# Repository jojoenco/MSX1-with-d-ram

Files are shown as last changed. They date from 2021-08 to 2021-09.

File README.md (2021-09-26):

# MSX1-with-d-ram
MSX1 compatible machine with old fashion D-Ram

Specs:  
Z80  
TMS9918 (composiet out)  
8255  
AY-3-8910  
HM4816 X8 V-Ram  
HM4864 X8 Ram  
74xx  logic IC's  

Tested until version 2.5 
This is version 2.6 should work as I only removed the Opamp for audio out and chanced the Transistor for the (Cassete)relay that
probably nobody uses. (because there is also a jack in and out for the cassete)

What works and tested in version 2.5:
- [x] Boot with MSX-Bios and C-Bios 
- [x] Video Out
- [x] audio out (sound was bad in version 2.5 so removed Opamp in 2.6)
- [x] Joystick ports
- [x] cassete in through 3.5"mm jack
- [ ] cassete out not tested
- [ ] Cassete DIN not tested
- [ ] relay (for Cassete REM) did not switch in version 2.5 (chanced transistor but not tested yet)
- [x] reset
- [X] Keyboard 
- [X] Cartridge Slot 1 and Slot2
- [ ] Printer port not tested

Because there is only a matrix connection for the keyboard I used the keyboard from Sergey Kiselev (github.com/skiselev/omega) to test.
I used the keyboard without de chips on it because they are on the main board and I jumpered on U2 the pins 1-2 and 3-4 and 5-6 and 8-9.
And then connected the wires directly to U1 pin 1-9 and J1 the bottom row.

My own keyboard PCB is ready but I am waiting for the switches to test it.

THE KEYBOARD  
The switches came in and it works fine:  
https://github.com/jojoenco/Keyboard-for-MSX1-with-d-ram

Below a foto of version 2.0 

And more Below Version 2.6 with no components yet





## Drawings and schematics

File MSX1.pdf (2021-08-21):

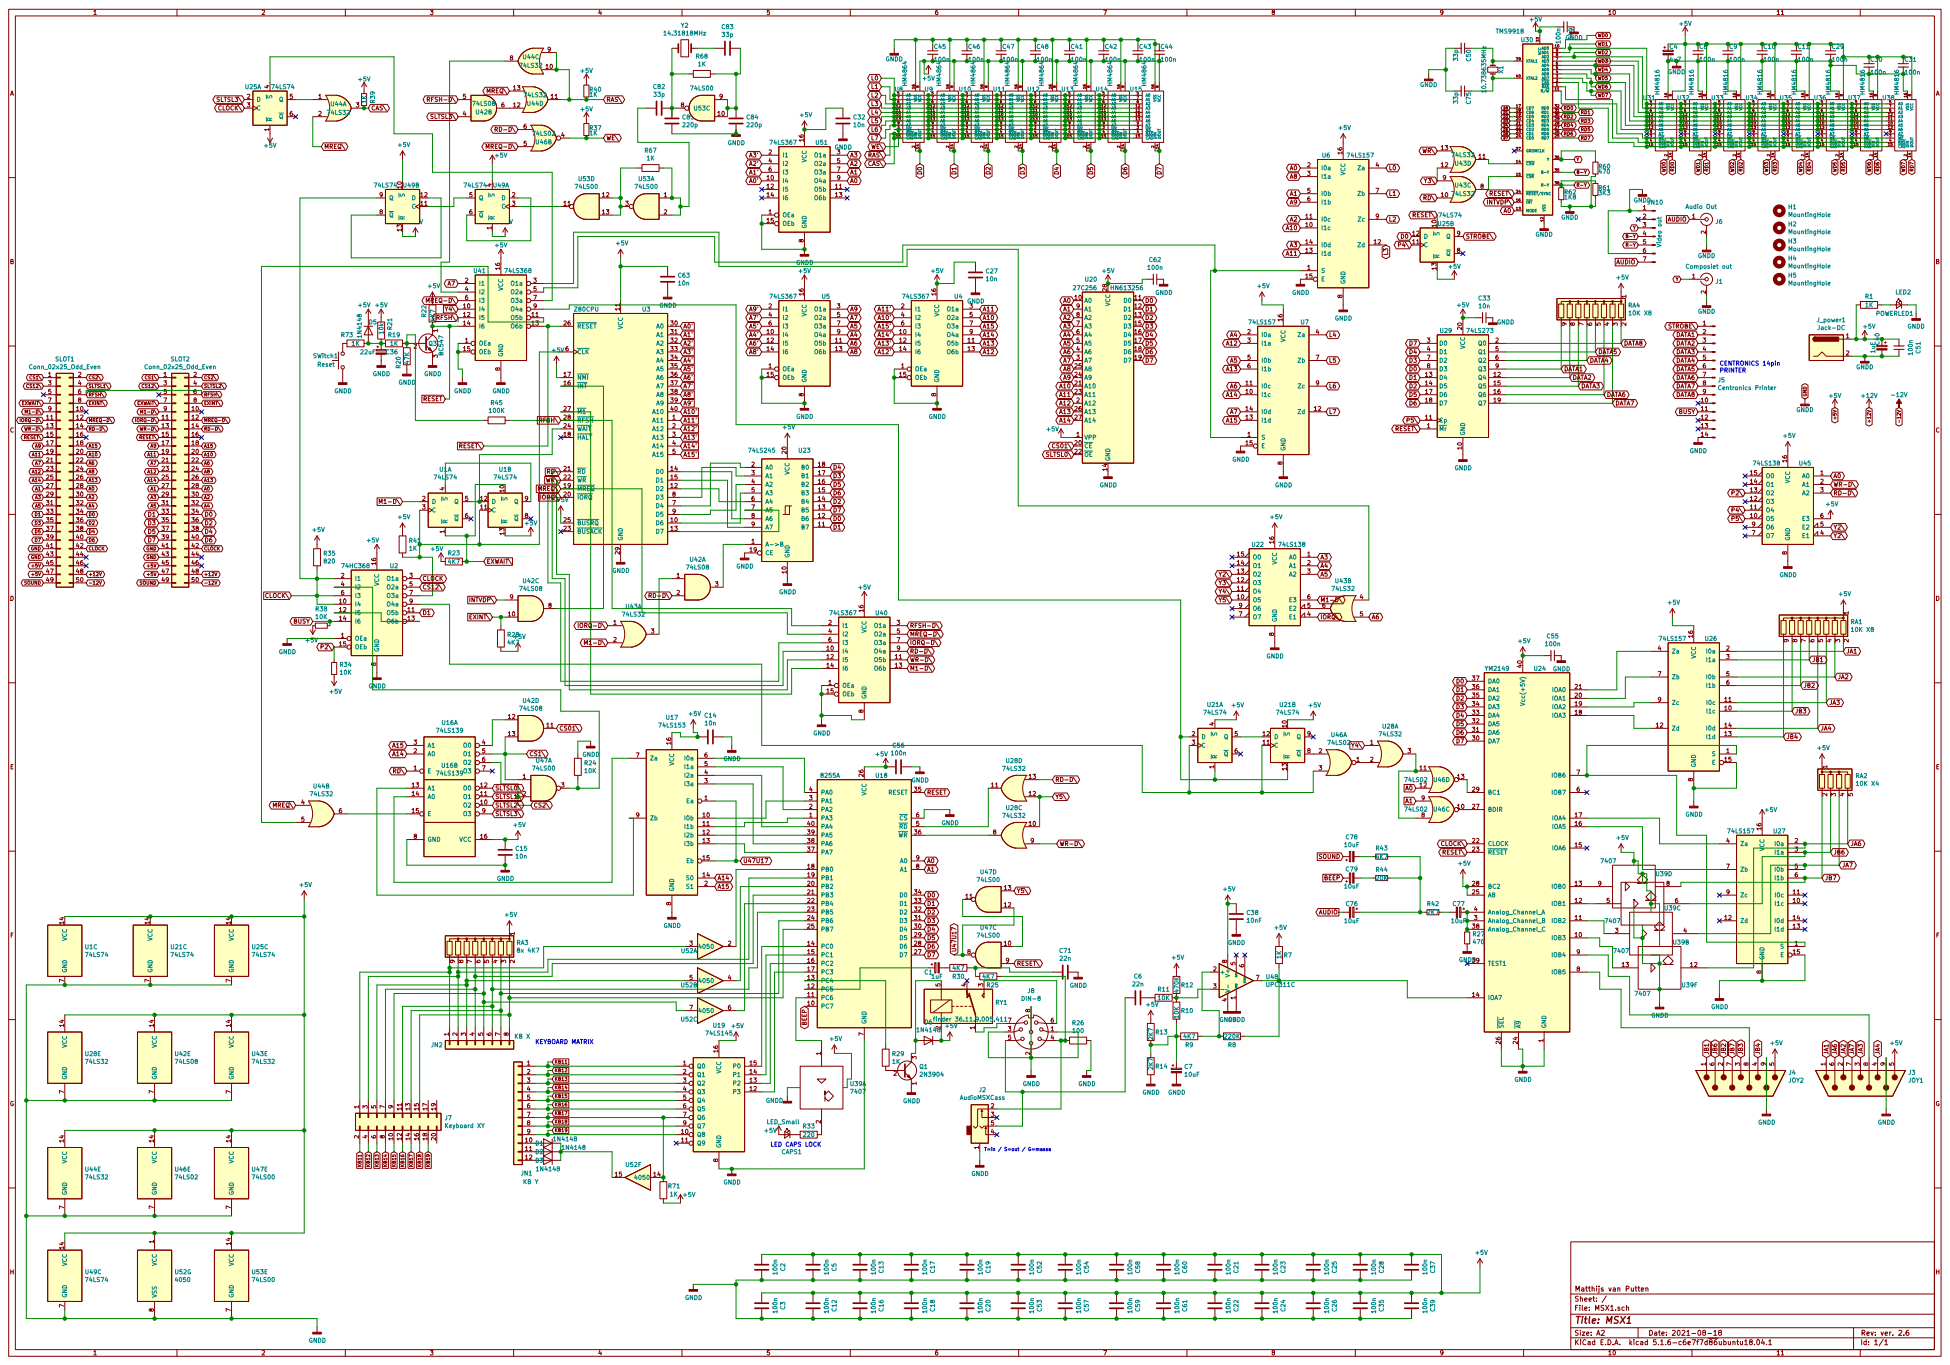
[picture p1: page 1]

8 A7 9 U10 HM4864 PA3 1 PC7 10 PC6 11 PC5 12 PC4 13 PC0 14 PC1 15 PC2 16 PC3 17 PB0 18 PB1 19 PA2 2 PB2 20 PB3 21 PB4 22 PB5 23 PB6 24 PB7 25 VCC 26 D7 27 D6 28 D5 29 PA1 3 D4 30 D3 31 D2 32 D1 33 D0 34 RESET 35 WR 36 PA7 37 PA6 38 PA5 39 PA0 4 PA4 40 RD 5 CS 6 GND

J6 Audio Out VCC 14 GND

T=in / S=out / G=massa KEYBOARD MATRIX

Id: 1/1 Title: MSX1 File: MSX1.sch Sheet: / Matthijs van Putten

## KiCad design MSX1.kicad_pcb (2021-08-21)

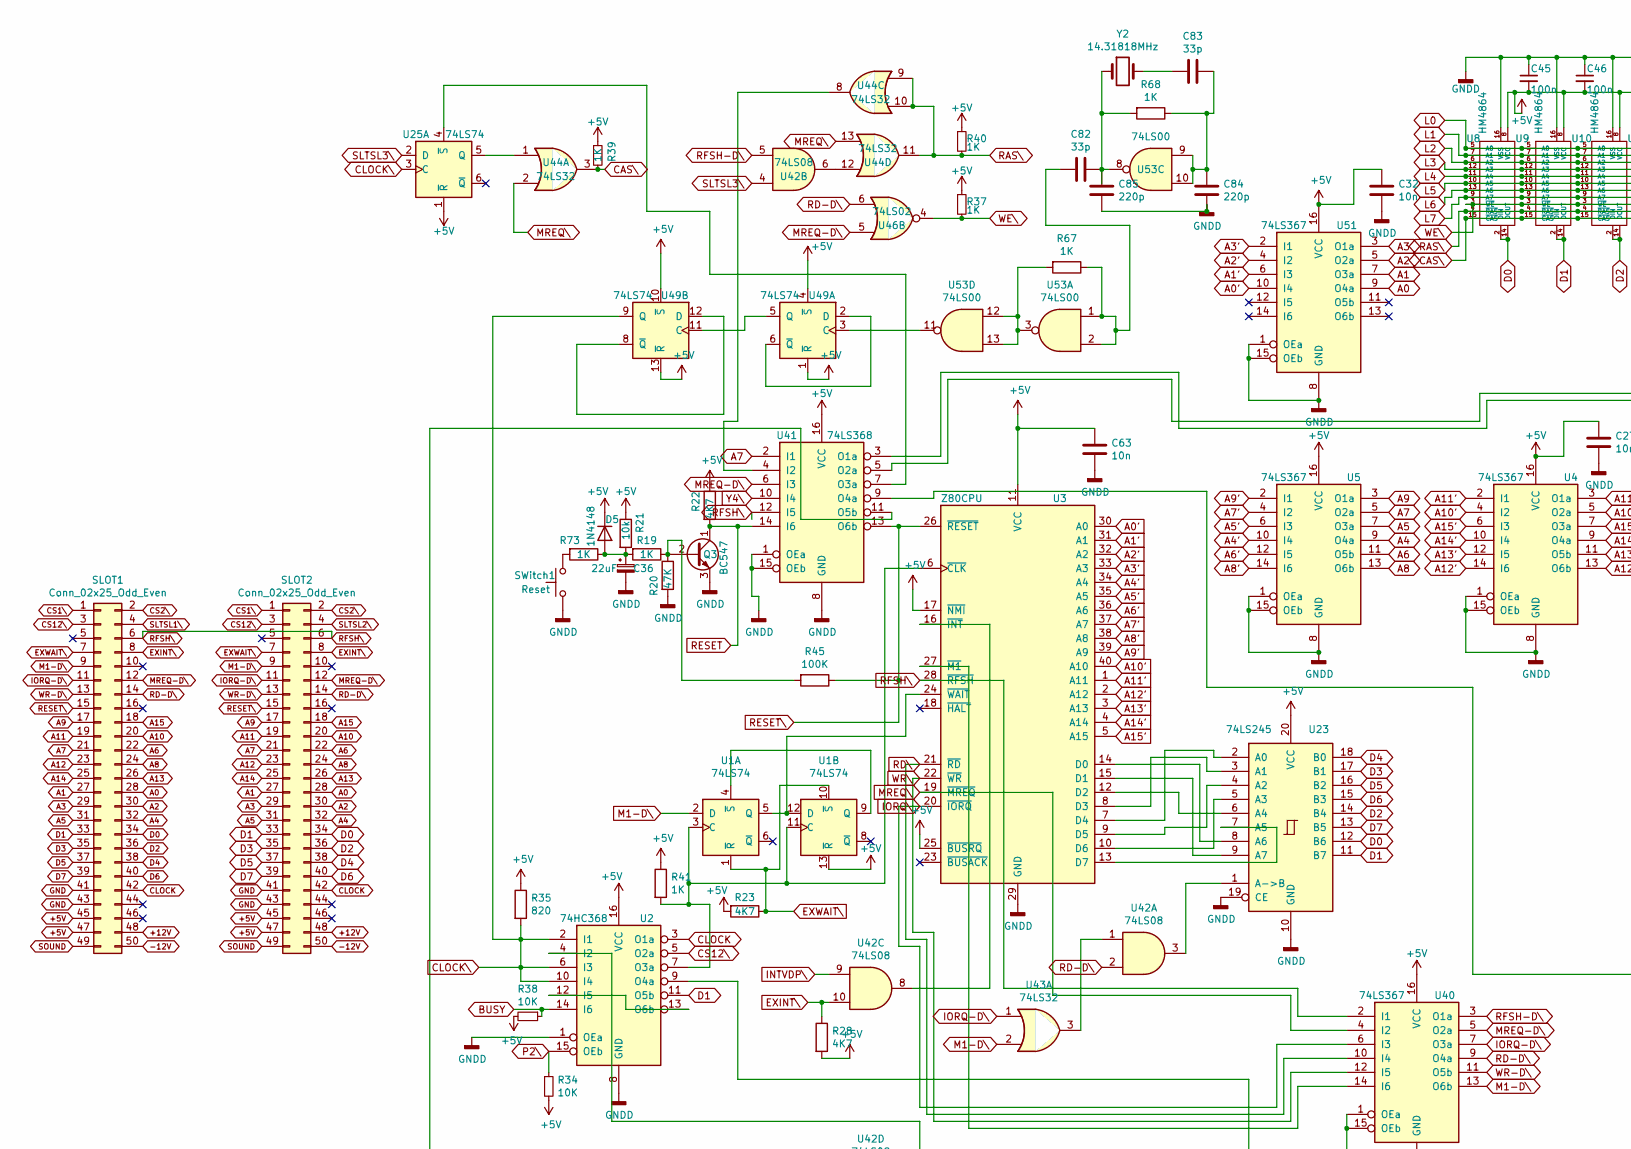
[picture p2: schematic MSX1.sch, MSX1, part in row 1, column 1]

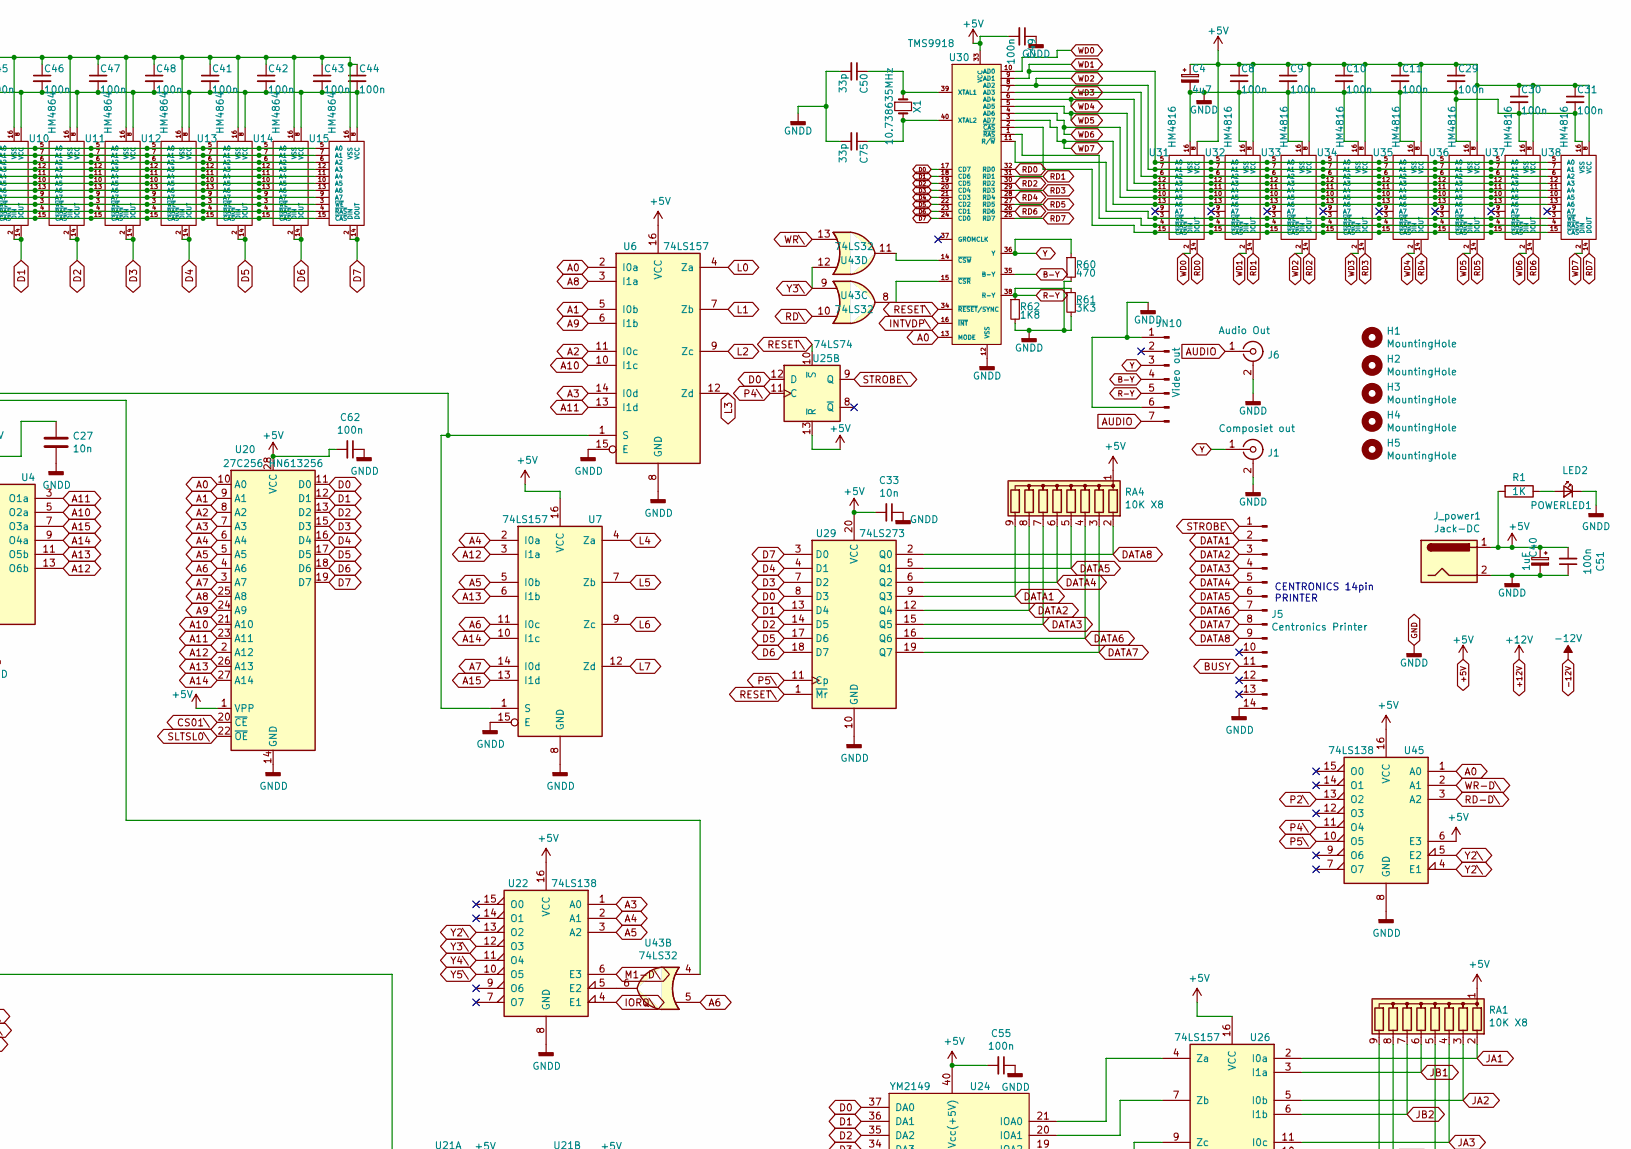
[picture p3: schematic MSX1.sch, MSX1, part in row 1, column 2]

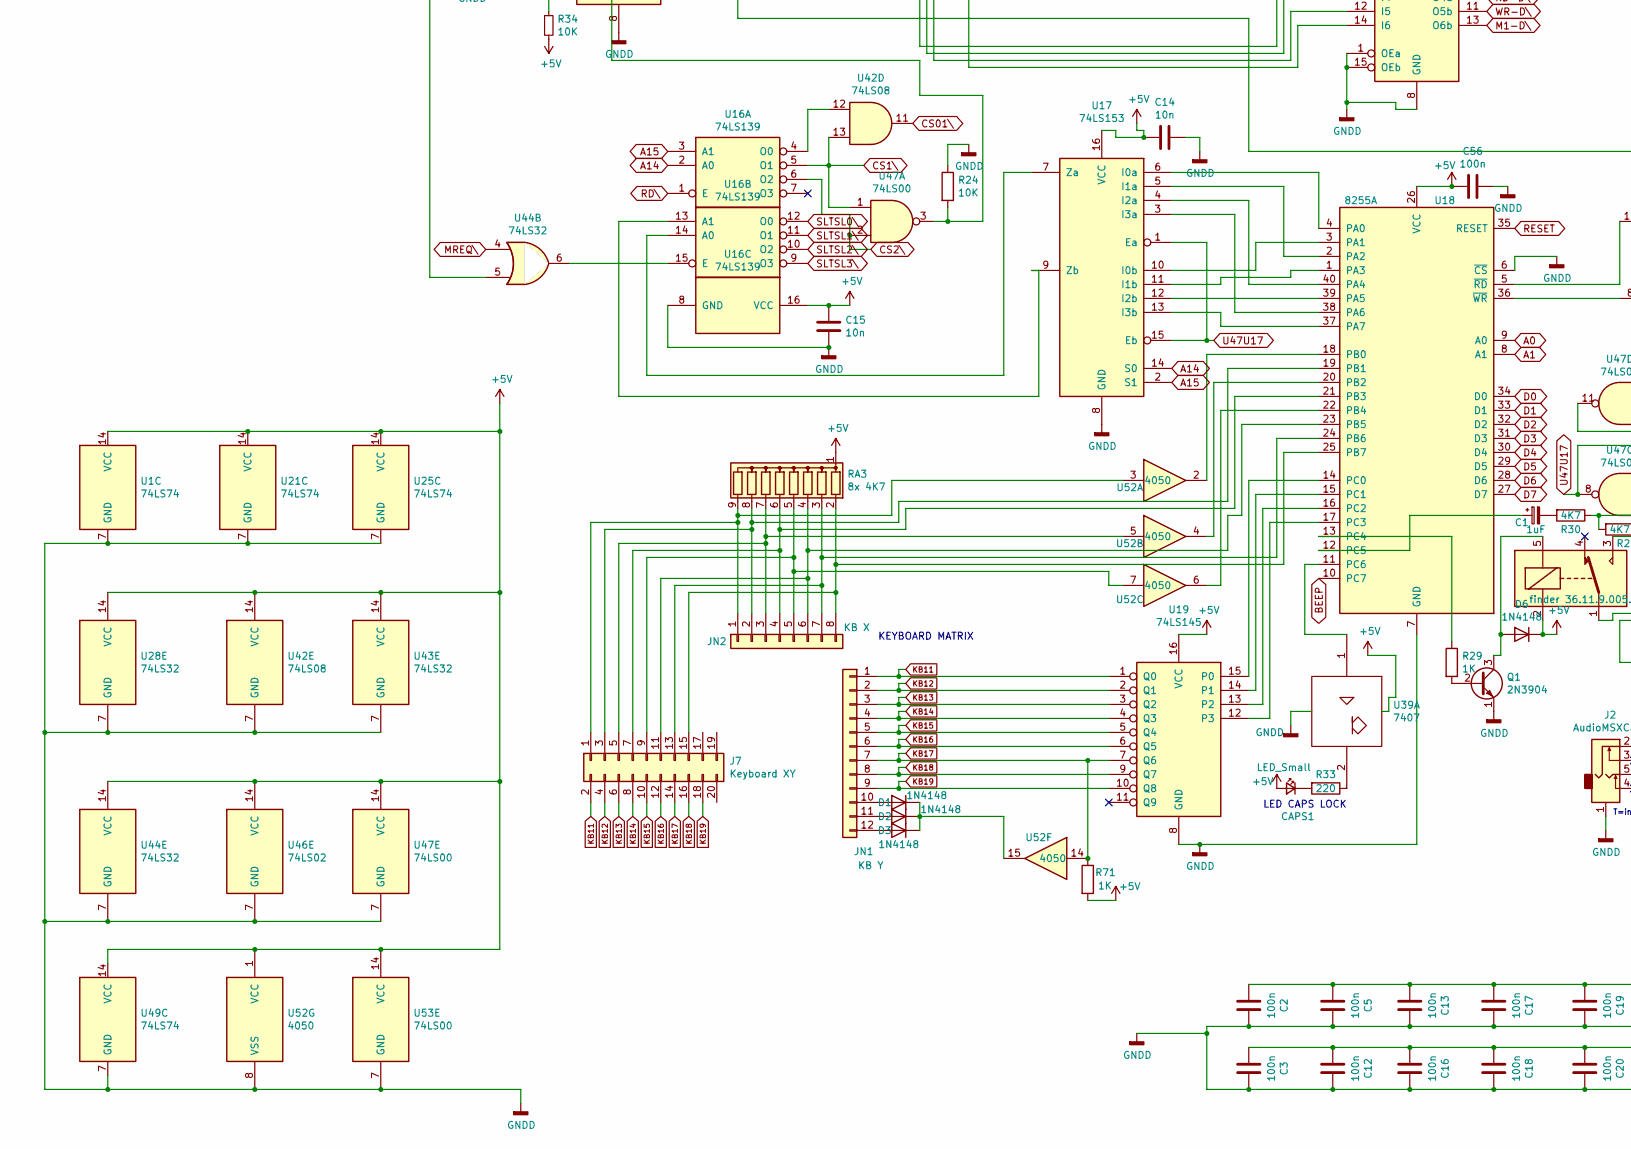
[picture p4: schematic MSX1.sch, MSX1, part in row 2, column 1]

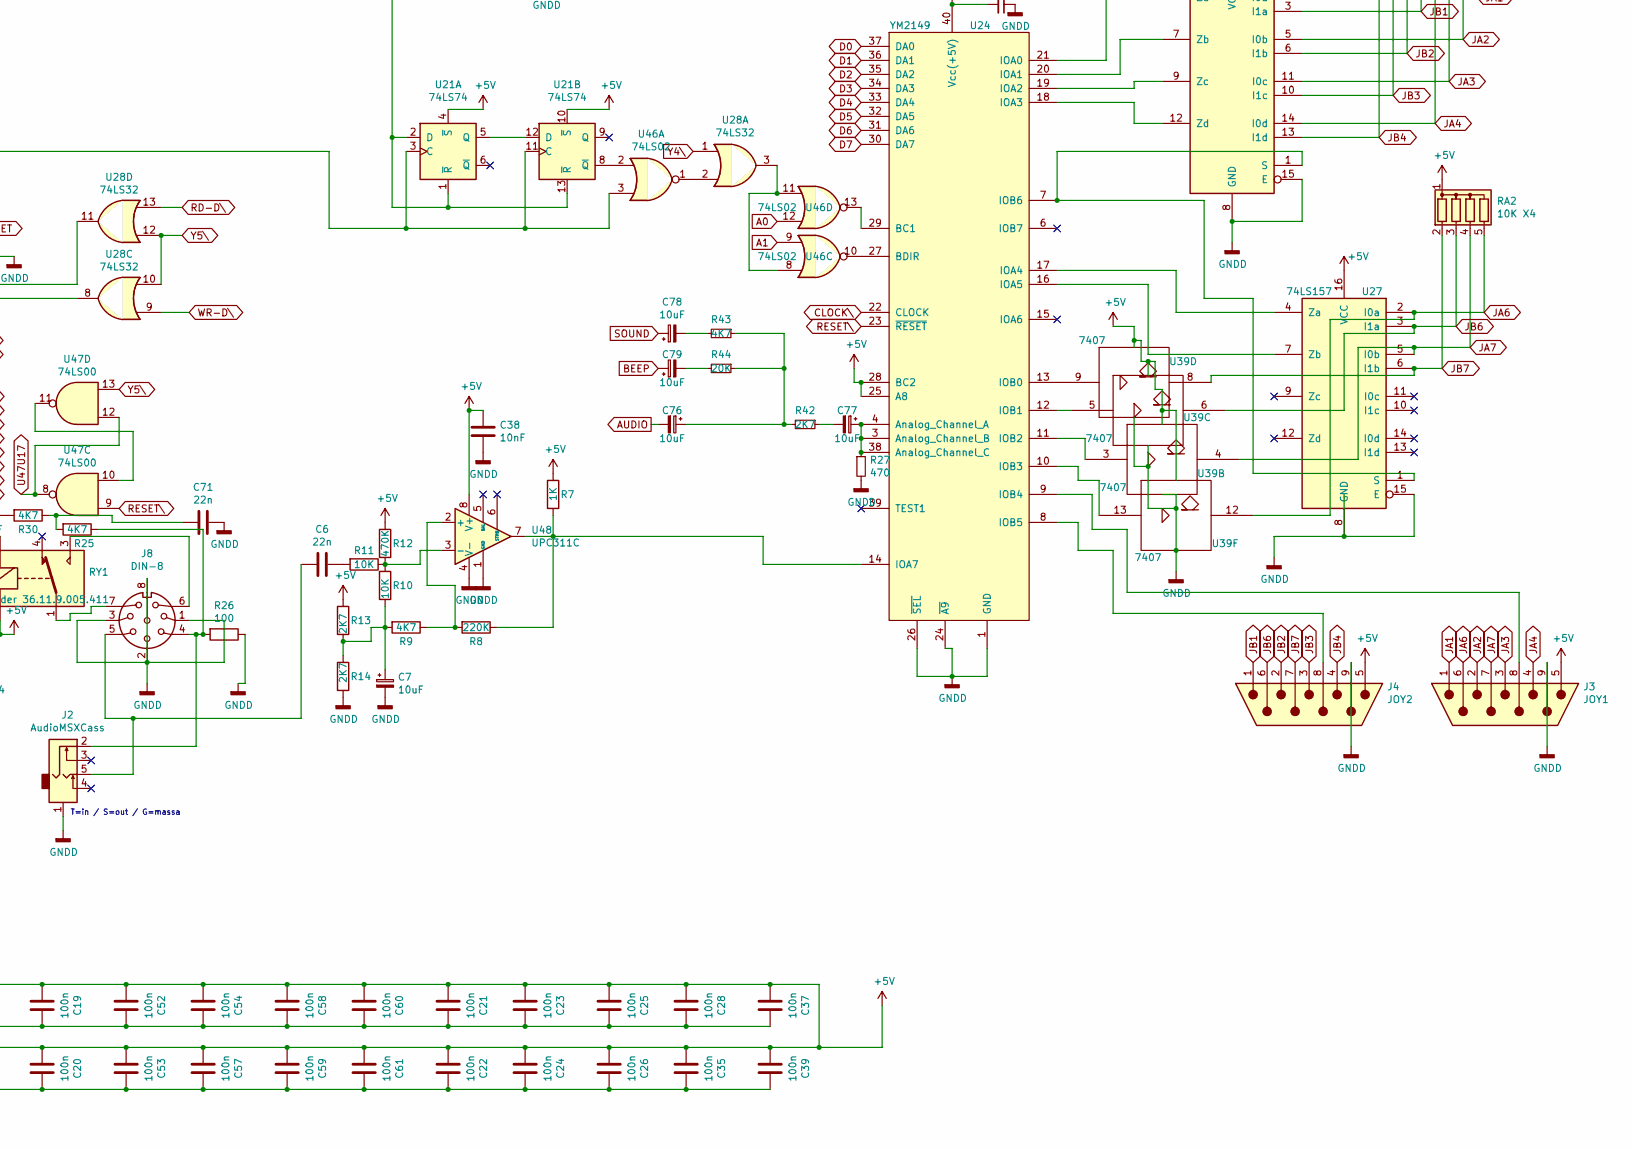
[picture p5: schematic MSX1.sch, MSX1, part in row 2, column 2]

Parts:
C1, C40: 1uF; CP_Radial_D4.0mm_P1.50mm
C2, C3, C5, C8, C9, C10, C11, C12, C13, C16, C17, C18, C19, C20, C21, C22, C23, C24, C25, C26, C28, C29, C30, C31, C35, C37, C39, C41, C42, C43, C44, C45, C46, C47, C48, C49, C51, C52, C53, C54, C55, C56, C57, C58, C59, C60, C61, C62: 100n; C_Disc_D4.3mm_W1.9mm_P5.00mm
C4: 4u7; CP_Radial_D4.0mm_P1.50mm
C6, C71: 22n; C_Disc_D4.3mm_W1.9mm_P5.00mm
C7, C76, C77, C78, C79: 10uF; CP_Radial_D4.0mm_P1.50mm
C14, C15, C27, C32, C33, C63: 10n; C_Disc_D4.3mm_W1.9mm_P5.00mm
C36: 22uF; CP_Radial_D4.0mm_P1.50mm
C38: 10nF; C_Disc_D4.3mm_W1.9mm_P5.00mm
C50, C75, C82, C83: 33p; C_Disc_D4.3mm_W1.9mm_P5.00mm
C84, C85: 220p; C_Disc_D4.3mm_W1.9mm_P5.00mm
CAPS1: LED_Small; LED_D5.0mm
D1, D2, D3, D5, D6: 1N4148; D_A-405_P7.62mm_Horizontal
H1, H2, H3, H4, H5: MountingHole; MountingHole_4.3mm_M4
J1: Composiet out; RCA FeMale
J2: AudioMSXCass; Jack_conn_audio
J3: JOY1; DSUB-9_Male_Horizontal_Pitch2.77x2.84mm_EdgePinOffset4.94mm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
J4: JOY2; DSUB-9_Male_Horizontal_Pitch2.77x2.84mm_EdgePinOffset4.94mm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
J5: Centronics Printer; Multicomp_MC9A12-1434_2x07x2.54mm_Straight
J6: Audio Out; RCA FeMale
J7: Keyboard XY; IDC-Header_2x10_P2.54mm_Vertical
J8: DIN-8; DIN 8 PIN 270gr round Chassis
JN1: KB Y; Pin_Header_Straight_1x12_Pitch2.54mm
JN2: KB X; Pin_Header_Straight_1x08_Pitch2.54mm
JN10: Video out; Pin_Header_Straight_1x07_Pitch2.54mm
J_power1: Jack-DC; BarrelJack_Wuerth_6941xx301002
POWERLED1: LED2; LED_D5.0mm
Q1: 2N3904; TO-92
Q3: BC547; TO-92
R1, R7, R19, R29, R37, R39, R40, R41, R67, R68, R71, R73: 1K; R_Axial_DIN0207_L6.3mm_D2.5mm_P7.62mm_Horizontal
R8: 220K; R_Axial_DIN0207_L6.3mm_D2.5mm_P7.62mm_Horizontal
R9, R22, R23, R25, R28, R30, R43: 4K7; R_Axial_DIN0207_L6.3mm_D2.5mm_P7.62mm_Horizontal
R10, R11, R24, R34, R38: 10K; R_Axial_DIN0207_L6.3mm_D2.5mm_P7.62mm_Horizontal
R12: 470K; R_Axial_DIN0207_L6.3mm_D2.5mm_P7.62mm_Horizontal
R13, R14, R42: 2K7; R_Axial_DIN0207_L6.3mm_D2.5mm_P7.62mm_Horizontal
R20: 47K; R_Axial_DIN0207_L6.3mm_D2.5mm_P7.62mm_Horizontal
R21: 10k; R_Axial_DIN0207_L6.3mm_D2.5mm_P7.62mm_Horizontal
R26: 100; R_Axial_DIN0207_L6.3mm_D2.5mm_P7.62mm_Horizontal
R27, R60: 470; R_Axial_DIN0207_L6.3mm_D2.5mm_P7.62mm_Horizontal
R33: 220; R_Axial_DIN0207_L6.3mm_D2.5mm_P7.62mm_Horizontal
R35: 820; R_Axial_DIN0207_L6.3mm_D2.5mm_P7.62mm_Horizontal
R44: 20K; R_Axial_DIN0207_L6.3mm_D2.5mm_P7.62mm_Horizontal
R45: 100K; R_Axial_DIN0207_L6.3mm_D2.5mm_P7.62mm_Horizontal
R61: 3K3; R_Axial_DIN0207_L6.3mm_D2.5mm_P7.62mm_Horizontal
R62: 1K8; R_Axial_DIN0207_L6.3mm_D2.5mm_P7.62mm_Horizontal
RA1, RA4: 10K X8; R_Array_SIP9
RA2: 10K X4; R_Array_SIP5
RA3: 8x 4K7; R_Array_SIP9
RY1: finder 36.11.9.005.411; Relay_SPDT_OMRON-G5LE-1
SLOT1, SLOT2: Conn_02x25_Odd_Even; Slot_conn
SWitch1: Reset; SW_Tactile_SPST_Angled_PTS645Vx39-2LFS
U1, U21, U25, U49: 74LS74; DIP-14_W7.62mm_Socket
U2: 74HC368; DIP-16_W7.62mm_Socket
U3: Z80CPU; DIP-40_W15.24mm
U4, U5, U40, U51: 74LS367; DIP-16_W7.62mm_Socket
U6, U7, U26, U27: 74LS157; DIP-16_W7.62mm_Socket
U8, U9, U10, U11, U12, U13, U14, U15: HM4864; DIP-16_W7.62mm_Socket
U16: 74LS139; DIP-16_W7.62mm_Socket
U17: 74LS153; DIP-16_W7.62mm_Socket
U18: 8255A; DIP-40_W15.24mm_Socket
U19: 74LS145; DIP-16_W7.62mm_Socket
U20: 27C256 HN613256; DIP-28_W15.24mm_Socket
U22, U45: 74LS138; DIP-16_W7.62mm_Socket
U23: 74LS245; DIP-20_W7.62mm_Socket
U24: YM2149; DIP-40_W15.24mm
U28, U43, U44: 74LS32; DIP-14_W7.62mm_Socket
U29: 74LS273; DIP-20_W7.62mm_Socket
U30: TMS9918; DIP-40_W15.24mm
U31, U32, U33, U34, U35, U36, U37, U38: HM4816; DIP-16_W7.62mm_Socket
U39: 7407; DIP-14_W7.62mm_Socket
U41: 74LS368; DIP-16_W7.62mm_Socket
U42: 74LS08; DIP-14_W7.62mm_Socket
U46: 74LS02; DIP-14_W7.62mm_Socket
U47, U53: 74LS00; DIP-14_W7.62mm_Socket
U48: UPC311C; DIP-8_W7.62mm_Socket
U52: 4050; DIP-16_W7.62mm_Socket
X1: 10.738635MHz; Crystal_HC49-4H_Vertical
Y2: 14.31818MHz; Crystal_HC49-4H_Vertical

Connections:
+5V: C2.2, C3.2, C4.1, C5.2, C8.1, C9.1, C10.1, C11.1, C12.2, C13.2, C14.2, C15.1, C16.2, C17.2, C18.2, C19.2, C20.2, C21.2, C22.2, C23.2, C24.2, C25.2, C26.2, C27.1, C28.2, C29.1, C30.1, C31.1, C32.1, C33.2, C35.2, C37.2, C38.1, C39.2, C40.1, C41.2, C42.2, C43.2, C44.2, C45.2, C46.2, C47.2, C48.2, C49.2, C51.2, C52.2, C53.2, C54.2, C55.2, C56.2, C57.2, C58.2, C59.2, C60.2, C61.2, C62.2, C63.1, CAPS1.2 (A), D5.1 (K), D6.1 (K), J3.5, J4.5, J_power1.1, R1.2, R7.1, R12.1, R13.1, R21.1, R22.1, R23.2, R28.2, R34.2, R35.1, R37.1, R38.2, R39.1, R40.1, R41.1, R71.2, RA1.1 (common), RA2.1 (common), RA3.1 (common), RA4.1 (common), RY1.2, SLOT1.45, SLOT1.47, SLOT2.45, SLOT2.47, U1.13 (~R), U1.14 (VCC), U2.16 (VCC), U3.11 (VCC), U3.17 (~NMI~), U3.25 (~BUSRQ~), U4.16 (VCC), U5.16 (VCC), U6.16 (VCC), U7.16 (VCC), U8.8 (VCC), U9.8 (VCC), U10.8 (VCC), U11.8 (VCC), U12.8 (VCC), U13.8 (VCC), U14.8 (VCC), U15.8 (VCC), U16.16 (VCC), U17.16 (VCC), U18.26 (VCC), U19.16 (VCC), U20.1 (VPP), U20.28 (VCC), U21.4 (~S), U21.10 (~S), U21.14 (VCC), U22.16 (VCC), U23.20 (VCC), U24.25 (A8), U24.28 (BC2), U24.40 (Vcc(+5V)), U25.1 (~R), U25.13 (~R), U25.14 (VCC), U26.16 (VCC), U27.16 (VCC), U28.14 (VCC), U29.20 (VCC), U30.33 (VCC), U31.8 (VCC), U32.8 (VCC), U33.8 (VCC), U34.8 (VCC), U35.8 (VCC), U36.8 (VCC), U37.8 (VCC), U38.8 (VCC), U39.14 (VCC), U40.16 (VCC), U41.16 (VCC), U42.14 (VCC), U43.14 (VCC), U44.14 (VCC), U45.6 (E3), U45.16 (VCC), U46.14 (VCC), U47.14 (VCC), U48.8 (V+), U49.1 (~R), U49.4 (~S), U49.10 (~S), U49.13 (~R), U49.14 (VCC), U51.16 (VCC), U52.1 (VCC), U53.14 (VCC)
+12V: SLOT1.48, SLOT2.48
-12V: SLOT1.50, SLOT2.50
A0: SLOT1.28, SLOT2.28, U6.2 (I0a), U18.9 (A0), U20.10 (A0), U30.13 (MODE), U45.1 (A0), U46.12, U51.9 (O4a)
A0': U3.30 (A0), U51.10 (I4)
A1: SLOT1.27, SLOT2.27, U6.5 (I0b), U18.8 (A1), U20.9 (A1), U46.9, U51.7 (O3a)
A1': U3.31 (A1), U51.6 (I3)
A2: SLOT1.30, SLOT2.30, U6.11 (I0c), U20.8 (A2), U51.5 (O2a)
A2': U3.32 (A2), U51.4 (I2)
A3: SLOT1.29, SLOT2.29, U6.14 (I0d), U20.7 (A3), U22.1 (A0), U51.3 (O1a)
A3': U3.33 (A3), U51.2 (I1)
A4: SLOT1.32, SLOT2.32, U5.9 (O4a), U7.2 (I0a), U20.6 (A4), U22.2 (A1)
A4': U3.34 (A4), U5.10 (I4)
A5: SLOT1.31, SLOT2.31, U5.7 (O3a), U7.5 (I0b), U20.5 (A5), U22.3 (A2)
A5': U3.35 (A5), U5.6 (I3)
A6: SLOT1.22, SLOT2.22, U5.11 (O5b), U7.11 (I0c), U20.4 (A6), U43.5
A6': U3.36 (A6), U5.12 (I5)
A7: SLOT1.21, SLOT2.21, U5.5 (O2a), U7.14 (I0d), U20.3 (A7), U41.2 (I1)
A7': U3.37 (A7), U5.4 (I2)
A8: SLOT1.24, SLOT2.24, U5.13 (O6b), U6.3 (I1a), U20.25 (A8)
A8': U3.38 (A8), U5.14 (I6)
A9: SLOT1.17, SLOT2.17, U5.3 (O1a), U6.6 (I1b), U20.24 (A9)
A9': U3.39 (A9), U5.2 (I1)
A10: SLOT1.20, SLOT2.20, U4.5 (O2a), U6.10 (I1c), U20.21 (A10)
A10': U3.40 (A10), U4.4 (I2)
A11: SLOT1.19, SLOT2.19, U4.3 (O1a), U6.13 (I1d), U20.23 (A11)
A11': U3.1 (A11), U4.2 (I1)
A12: SLOT1.23, SLOT2.23, U4.13 (O6b), U7.3 (I1a), U20.2 (A12)
A12': U3.2 (A12), U4.14 (I6)
A13: SLOT1.26, SLOT2.26, U4.11 (O5b), U7.6 (I1b), U20.26 (A13)
A13': U3.3 (A13), U4.12 (I5)
A14: SLOT1.25, SLOT2.25, U4.9 (O4a), U7.10 (I1c), U16.2 (A0), U17.14 (S0), U20.27 (A14)
A14': U3.4 (A14), U4.10 (I4)
A15: SLOT1.18, SLOT2.18, U4.7 (O3a), U7.13 (I1d), U16.3 (A1), U17.2 (S1)
A15': U3.5 (A15), U4.6 (I3)
AUDIO: C76.2, J6.1 (In), JN10.7
B-Y: JN10.4, U30.35 (B-Y)
BEEP: C79.1, U18.10 (PC7)
BUSY: J5.11, R38.1, U2.14 (I6)
CAS\: R39.2, U8.15 (~CAS), U9.15 (~CAS), U10.15 (~CAS), U11.15 (~CAS), U12.15 (~CAS), U13.15 (~CAS), U14.15 (~CAS), U15.15 (~CAS), U44.3
CLOCK: SLOT1.42, SLOT2.42, U2.3 (O1a)
CLOCK\: R35.2, U2.2 (I1), U2.6 (I3), U2.10 (I4), U24.22 (CLOCK), U25.3 (C), U49.9 (Q)
CS1\: SLOT1.1, SLOT2.1, U16.5 (O1), U42.13, U47.1
CS01\: U20.20 (~CE), U42.11
CS2\: SLOT1.2, SLOT2.2, U16.6 (O2), U47.2
CS12\: SLOT1.3, SLOT2.3, U2.5 (O2a)
D0: SLOT1.34, SLOT2.34, U8.2 (DIN), U8.14 (DOUT), U18.34 (D0), U20.11 (D0), U23.12 (B6), U24.37 (DA0), U25.12 (D), U29.8 (D3), U30.17 (CD7)
D1: SLOT1.33, SLOT2.33, U2.11 (O5b), U9.2 (DIN), U9.14 (DOUT), U18.33 (D1), U20.12 (D1), U23.11 (B7), U24.36 (DA1), U29.13 (D4), U30.18 (CD6)
D2: SLOT1.36, SLOT2.36, U10.2 (DIN), U10.14 (DOUT), U18.32 (D2), U20.13 (D2), U23.14 (B4), U24.35 (DA2), U29.14 (D5), U30.19 (CD5)
D3: SLOT1.35, SLOT2.35, U11.2 (DIN), U11.14 (DOUT), U18.31 (D3), U20.15 (D3), U23.17 (B1), U24.34 (DA3), U29.7 (D2), U30.20 (CD4)
D4: SLOT1.38, SLOT2.38, U12.2 (DIN), U12.14 (DOUT), U18.30 (D4), U20.16 (D4), U23.18 (B0), U24.33 (DA4), U29.4 (D1), U30.21 (CD3)
D5: SLOT1.37, SLOT2.37, U13.2 (DIN), U13.14 (DOUT), U18.29 (D5), U20.17 (D5), U23.16 (B2), U24.32 (DA5), U29.17 (D6), U30.22 (CD2)
D6: SLOT1.40, SLOT2.40, U14.2 (DIN), U14.14 (DOUT), U18.28 (D6), U20.18 (D6), U23.15 (B3), U24.31 (DA6), U29.18 (D7), U30.23 (CD1)
D7: SLOT1.39, SLOT2.39, U15.2 (DIN), U15.14 (DOUT), U18.27 (D7), U20.19 (D7), U23.13 (B5), U24.30 (DA7), U29.3 (D0), U30.24 (CD0)
DATA1: J5.2, RA4.9 (R8), U29.9 (Q3)
DATA2: J5.3, RA4.8 (R7), U29.12 (Q4)
DATA3: J5.4, RA4.7 (R6), U29.15 (Q5)
DATA4: J5.5, RA4.6 (R5), U29.6 (Q2)
DATA5: J5.6, RA4.5 (R4), U29.5 (Q1)
DATA6: J5.7, RA4.4 (R3), U29.16 (Q6)
DATA7: J5.8, RA4.3 (R2), U29.19 (Q7)
DATA8: J5.9, RA4.2 (R1), U29.2 (Q0)
EXINT\: R28.1, SLOT1.8, SLOT2.8, U42.10
EXWAIT\: R23.1, SLOT1.7, SLOT2.7, U1.1 (~R), U1.10 (~S)
GND: C2.1, C3.1, C4.2, C5.1, C7.2, C8.2, C9.2, C10.2, C11.2, C12.1, C13.1, C14.1, C15.2, C16.1, C17.1, C18.1, C19.1, C20.1, C21.1, C22.1, C23.1, C24.1, C25.1, C26.1, C27.2, C28.1, C29.2, C30.2, C31.2, C32.2, C33.1, C35.1, C36.2, C37.1, C38.2, C39.1, C40.2, C41.1, C42.1, C43.1, C44.1, C45.1, C46.1, C47.1, C48.1, C49.1, C50.2, C51.1, C52.1, C53.1, C54.1, C55.1, C56.1, C57.1, C58.1, C59.1, C60.1, C61.1, C62.1, C63.2, C71.1, C75.2, C84.2, C85.2, J1.2 (Ext), J2.1, J3.9, J4.9, J5.14, J6.2 (Ext), J8.1, J8.2, J8.3, J8.8, JN10.1, JN10.6, J_power1.2, POWERLED1.1 (K), Q1.1 (E), Q3.3 (E), R14.2, R20.2, R24.1, R26.1, R27.2, R60.2, R61.2, R62.2, SLOT1.41, SLOT1.43, SLOT2.41, SLOT2.43, SWitch1.1, U1.7 (GND), U2.1 (OEa), U2.8 (GND), U3.29 (GND), U4.1 (OEa), U4.8 (GND), U4.15 (OEb), U5.1 (OEa), U5.8 (GND), U5.15 (OEb), U6.8 (GND), U6.15 (E), U7.8 (GND), U7.15 (E), U8.16 (VSS), U9.16 (VSS), U10.16 (VSS), U11.16 (VSS), U12.16 (VSS), U13.16 (VSS), U14.16 (VSS), U15.16 (VSS), U16.8 (GND), U17.8 (GND), U18.6 (~CS~), U18.7 (GND), U19.8 (GND), U20.14 (GND), U21.7 (GND), U22.8 (GND), U23.10 (GND), U23.19 (CE), U24.1 (GND), U24.24 (~A9), U24.26 (~SEL), U25.7 (GND), U26.8 (GND), U26.15 (E), U27.8 (GND), U27.15 (E), U28.7 (GND), U29.10 (GND), U30.12 (VSS), U31.16 (VSS), U32.16 (VSS), U33.16 (VSS), U34.16 (VSS), U35.16 (VSS), U36.16 (VSS), U37.16 (VSS), U38.16 (VSS), U39.7 (GND), U40.1 (OEa), U40.8 (GND), U40.15 (OEb), U41.1 (OEa), U41.8 (GND), U41.15 (OEb), U42.7 (GND), U43.7 (GND), U44.7 (GND), U45.8 (GND), U46.7 (GND), U47.7 (GND), U48.1 (GND), U48.4 (V-), U49.7 (GND), U51.1 (OEa), U51.8 (GND), U51.15 (OEb), U52.8 (VSS), U53.7 (GND)
INTVDP\: U30.16 (~INT), U42.9
IORQ-D\: SLOT1.11, SLOT2.11, U40.7 (O3a), U43.1
IORQ\: U3.20 (~IORQ~), U22.4 (E1), U40.6 (I3)
JA1: J3.1, RA1.2 (R1), U26.2 (I0a)
JA2: J3.2, RA1.3 (R2), U26.5 (I0b)
JA3: J3.3, RA1.4 (R3), U26.11 (I0c)
JA4: J3.4, RA1.5 (R4), U26.14 (I0d)
JA6: J3.6, RA2.5 (R4), U27.2 (I0a), U39.12
JA7: J3.7, RA2.4 (R3), U27.5 (I0b), U39.4
JB1: J4.1, RA1.6 (R5), U26.3 (I1a)
JB2: J4.2, RA1.7 (R6), U26.6 (I1b)
JB3: J4.3, RA1.8 (R7), U26.10 (I1c)
JB4: J4.4, RA1.9 (R8), U26.13 (I1d)
JB6: J4.6, RA2.3 (R2), U27.3 (I1a), U39.6
JB7: J4.7, RA2.2 (R1), U27.6 (I1b), U39.8
KB11: J7.2, JN1.1, U19.1 (Q0)
KB12: J7.4, JN1.2, U19.2 (Q1)
KB13: J7.6, JN1.3, U19.3 (Q2)
KB14: J7.8, JN1.4, U19.4 (Q3)
KB15: J7.10, JN1.5, U19.5 (Q4)
KB16: J7.12, JN1.6, U19.6 (Q5)
KB17: J7.14, JN1.7, R71.1, U19.7 (Q6), U52.14
KB18: J7.16, JN1.8, U19.9 (Q7)
KB19: J7.18, JN1.9, U19.10 (Q8)
L0: U6.4 (Za), U8.5 (A0), U9.5 (A0), U10.5 (A0), U11.5 (A0), U12.5 (A0), U13.5 (A0), U14.5 (A0), U15.5 (A0)
L1: U6.7 (Zb), U8.7 (A1), U9.7 (A1), U10.7 (A1), U11.7 (A1), U12.7 (A1), U13.7 (A1), U14.7 (A1), U15.7 (A1)
L2: U6.9 (Zc), U8.6 (A2), U9.6 (A2), U10.6 (A2), U11.6 (A2), U12.6 (A2), U13.6 (A2), U14.6 (A2), U15.6 (A2)
L3: U6.12 (Zd), U8.12 (A3), U9.12 (A3), U10.12 (A3), U11.12 (A3), U12.12 (A3), U13.12 (A3), U14.12 (A3), U15.12 (A3)
L4: U7.4 (Za), U8.11 (A4), U9.11 (A4), U10.11 (A4), U11.11 (A4), U12.11 (A4), U13.11 (A4), U14.11 (A4), U15.11 (A4)
L5: U7.7 (Zb), U8.10 (A5), U9.10 (A5), U10.10 (A5), U11.10 (A5), U12.10 (A5), U13.10 (A5), U14.10 (A5), U15.10 (A5)
L6: U7.9 (Zc), U8.13 (A6), U9.13 (A6), U10.13 (A6), U11.13 (A6), U12.13 (A6), U13.13 (A6), U14.13 (A6), U15.13 (A6)
L7: U7.12 (Zd), U8.9 (A7), U9.9 (A7), U10.9 (A7), U11.9 (A7), U12.9 (A7), U13.9 (A7), U14.9 (A7), U15.9 (A7)
M1-D\: SLOT1.9, SLOT2.9, U1.2 (D), U22.6 (E3), U40.13 (O6b), U43.2
MREQ-D\: SLOT1.12, SLOT2.12, U40.5 (O2a), U41.6 (I3), U46.5
MREQ\: U3.19 (~MREQ~), U40.4 (I2), U44.2, U44.4, U44.13
unnamed: C1.1, U18.12 (PC5)
unnamed: C1.2, R30.2
unnamed: C6.1, R11.2
unnamed: C6.2, J2.5, J8.5
unnamed: C7.1, R9.2, R10.2, R13.2, R14.1
unnamed: C36.1, D5.2 (A), R19.2, R21.2, R73.1
unnamed: C50.1, U30.39 (XTAL1), X1.1
unnamed: C71.2, R25.2, R30.1
unnamed: C75.1, U30.40 (XTAL2), X1.2
unnamed: C76.1, R42.2, R43.1, R44.1
unnamed: C77.1, R27.1, U24.3 (Analog_Channel_B), U24.4 (Analog_Channel_A), U24.38 (Analog_Channel_C)
unnamed: C77.2, R42.1
unnamed: C78.2, R43.2
unnamed: C79.2, R44.2
unnamed: C82.1, C85.1, R68.2, U53.8, Y2.1
unnamed: C82.2, R67.1, U53.1, U53.2
unnamed: C83.1, C84.1, R68.1, U53.9, U53.10
unnamed: C83.2, Y2.2
unnamed: CAPS1.1 (K), R33.2
unnamed: D1.1 (K), D2.1 (K), D3.1 (K), U52.15
unnamed: D1.2 (A), JN1.10
unnamed: D2.2 (A), JN1.11
unnamed: D3.2 (A), JN1.12
unnamed: D6.2 (A), Q1.3 (C), RY1.5
unnamed: J2.2, J8.4, R25.1, R26.2
unnamed: J3.8, U24.9 (IOB4)
unnamed: J4.8, U24.8 (IOB5)
unnamed: J7.1, JN2.1, RA3.9 (R8), U52.3
unnamed: J7.3, JN2.2, RA3.8 (R7), U18.19 (PB1)
unnamed: J7.5, JN2.3, RA3.7 (R6), U52.5
unnamed: J7.7, JN2.4, RA3.6 (R5), U18.21 (PB3)
unnamed: J7.9, JN2.5, RA3.5 (R4), U52.7
unnamed: J7.11, JN2.6, RA3.4 (R3), U18.23 (PB5)
unnamed: J7.13, JN2.7, RA3.3 (R2), U18.24 (PB6)
unnamed: J7.15, JN2.8, RA3.2 (R1), U18.25 (PB7)
unnamed: J8.6, RY1.3
unnamed: J8.7, RY1.1
unnamed: POWERLED1.2 (A), R1.1
unnamed: Q1.2 (B), R29.2
unnamed: Q3.2 (B), R19.1, R20.1, R45.2
unnamed: R7.2, R8.1, U24.14 (IOA7), U48.7
unnamed: R8.2, R9.1, U48.2 (+)
unnamed: R10.1, R11.1, R12.2, U48.3 (-)
unnamed: R24.2, U2.4 (I2), U47.3
unnamed: R29.1, U18.13 (PC4)
unnamed: R33.1, U39.2
unnamed: R41.2, U1.3 (C), U1.11 (C), U2.7 (O3a), U3.6 (~CLK~)
unnamed: R67.2, U53.3, U53.12, U53.13
unnamed: R73.2, SWitch1.2
unnamed: U1.4 (~S), U1.9 (Q)
unnamed: U1.5 (Q), U1.12 (D), U3.24 (~WAIT~)
unnamed: U2.9 (O4a), U21.3 (C), U21.11 (C), U46.3
unnamed: U2.12 (I5), U2.13 (O6b)
unnamed: U3.16 (~INT~), U42.8
unnamed: U3.27 (~M1~), U40.14 (I6)
unnamed: U16.4 (O0), U42.12
unnamed: U16.13 (A1), U17.9 (Zb)
unnamed: U16.14 (A0), U17.7 (Za)
unnamed: U16.15 (E), U44.6
unnamed: U17.3 (I3a), U18.38 (PA6)
unnamed: U17.4 (I2a), U18.40 (PA4)
unnamed: U17.5 (I1a), U18.2 (PA2)
unnamed: U17.6 (I0a), U18.4 (PA0)
unnamed: U17.10 (I0b), U18.3 (PA1)
unnamed: U17.11 (I1b), U18.1 (PA3)
unnamed: U17.12 (I2b), U18.39 (PA5)
unnamed: U17.13 (I3b), U18.37 (PA7)
unnamed: U18.5 (~RD~), U28.11
unnamed: U18.11 (PC6), U39.1
unnamed: U18.14 (PC0), U19.15 (P0)
unnamed: U18.15 (PC1), U19.14 (P1)
unnamed: U18.16 (PC2), U19.13 (P2)
unnamed: U18.17 (PC3), U19.12 (P3)
unnamed: U18.18 (PB0), U52.2
unnamed: U18.20 (PB2), U52.4
unnamed: U18.22 (PB4), U52.6
unnamed: U18.36 (~WR~), U28.8
unnamed: U21.1 (~R), U21.2 (D), U21.13 (~R), U41.9 (O4a)
unnamed: U21.8 (~Q), U46.2
unnamed: U21.5 (Q), U21.12 (D)
unnamed: U22.5 (E2), U43.6
unnamed: U23.1 (A->B), U42.3
unnamed: U3.7 (D4), U23.2 (A0)
unnamed: U3.8 (D3), U23.3 (A1)
unnamed: U3.9 (D5), U23.4 (A2)
unnamed: U3.10 (D6), U23.5 (A3)
unnamed: U3.12 (D2), U23.6 (A4)
unnamed: U3.13 (D7), U23.7 (A5)
unnamed: U3.14 (D0), U23.8 (A6)
unnamed: U3.15 (D1), U23.9 (A7)
unnamed: U24.7 (IOB6), U26.1 (S), U27.1 (S)
unnamed: U24.10 (IOB3), U39.13
unnamed: U24.11 (IOB2), U39.3
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

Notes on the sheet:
LED CAPS LOCK
KEYBOARD MATRIX
CENTRONICS 14pin PRINTER
T=in / S=out / G=massa

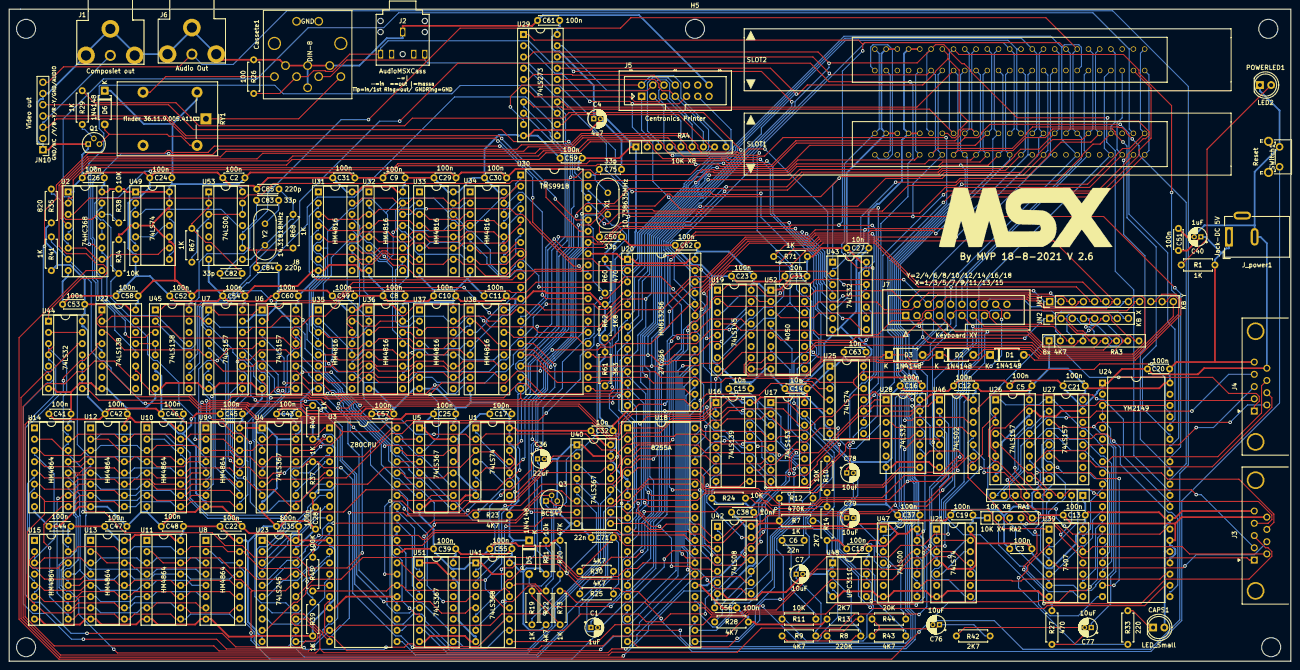
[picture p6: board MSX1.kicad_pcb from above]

Board: 2 copper layers, 289.6 x 147.3 mm, 200 parts (0 on the bottom side), 265 nets.
